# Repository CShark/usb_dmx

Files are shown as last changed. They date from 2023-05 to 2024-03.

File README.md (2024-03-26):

# USB ArtNET Interface

This project is a USB ArtNET interface with four ports, based on the STM32G484. It will register itself as an Ethernet Card using the CDC-NCM protocoll to be automatically recognized by most operating systems (except Windows 10, which needs some manual configuration). It will then bind the ArtNET-implementation to a configurable IP on that virtual ethernet card. The device can be configured either using ArtNET commands for software that supports this, using a web interface on the device and it can optionally be extended to include a display module for configuration directly at the device.

<p float="middle">
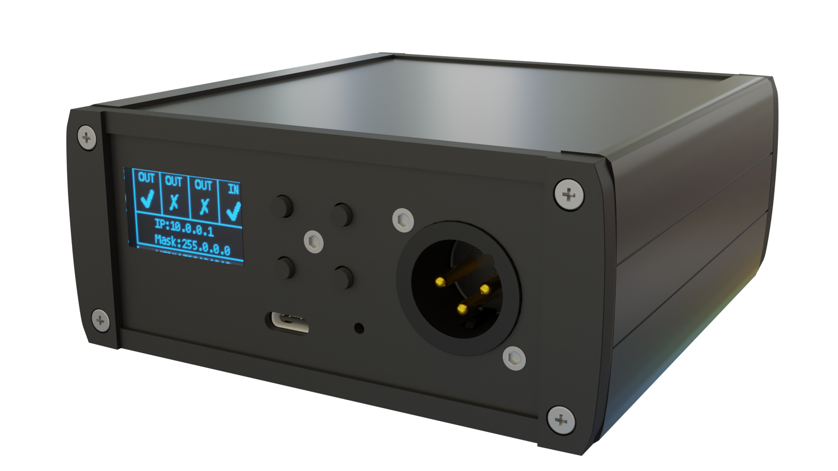
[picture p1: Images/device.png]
    
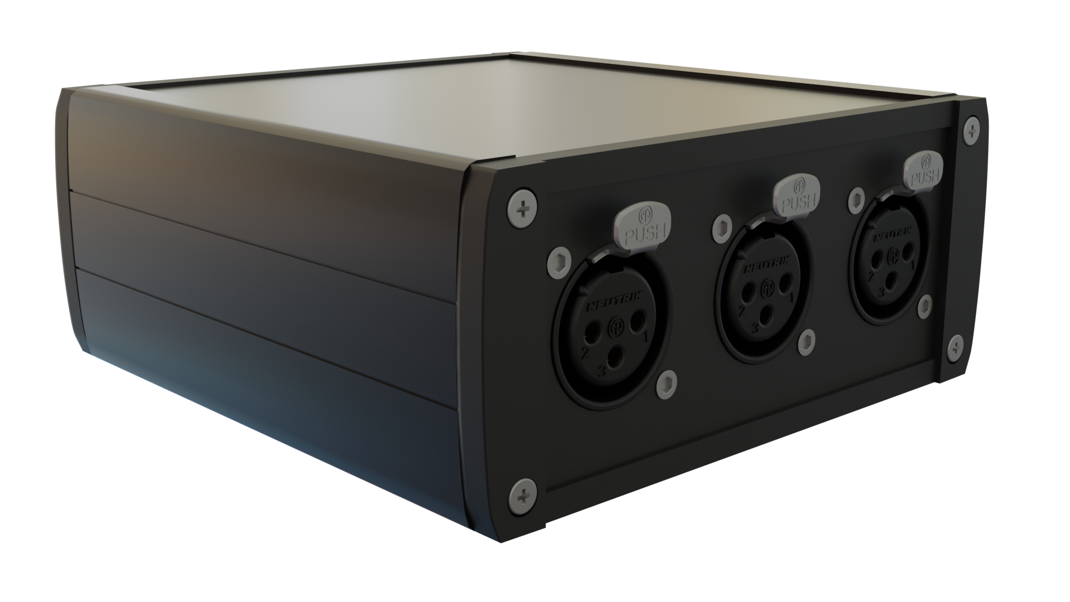
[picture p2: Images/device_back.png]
    
</p>
<p float="middle">
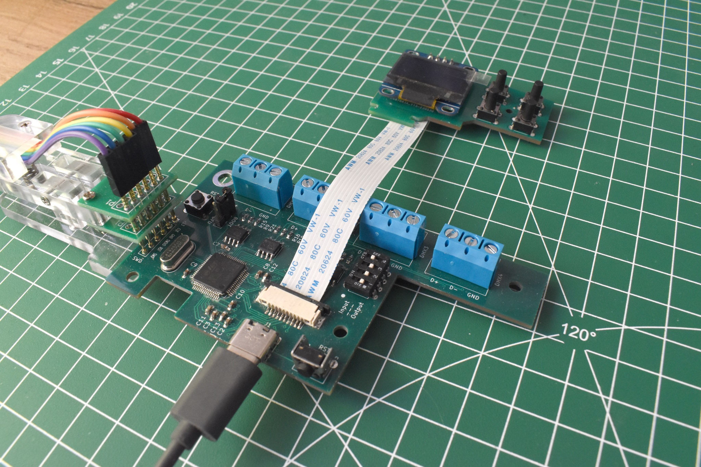
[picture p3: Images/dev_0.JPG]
    
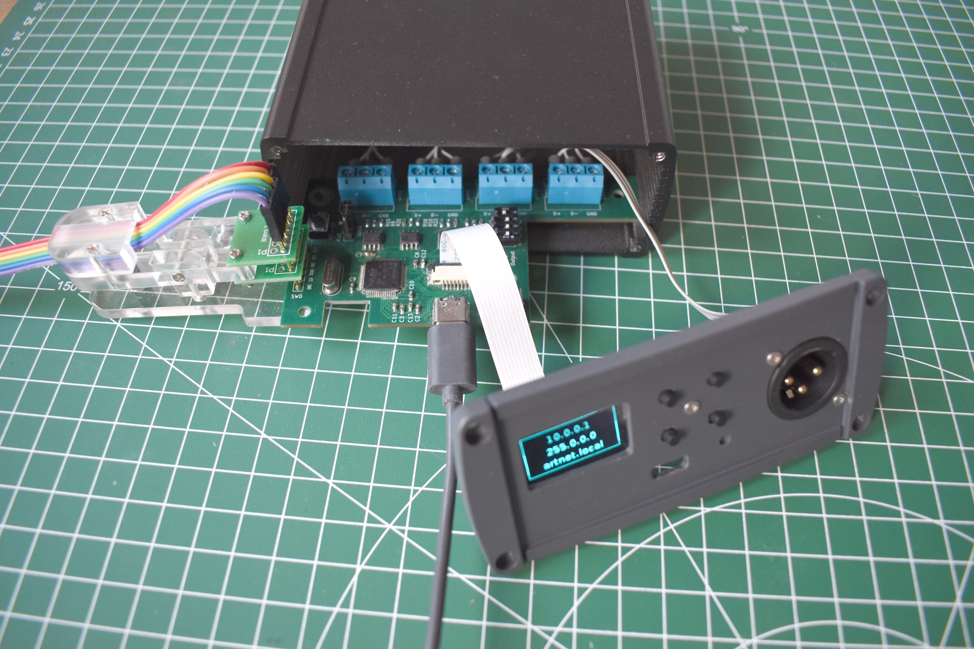
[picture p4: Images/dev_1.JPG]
    
</p>

## Schematic
The project uses an STM32G484RE, but should work with any STM32G4xxRE variant. The ports are controlled by a MAX3440E each, which will provide some ESD protection in addition to the TVS-Diodes. The device will draw around ~150mA, which is easily delivered by USB2.0 ports. Galvanic isolation was omitted because it needs too much space and because it is not recommended for the transmitting ports of DMX-Devices anyway (although it is recommended for receiving ports, but not mandatory).

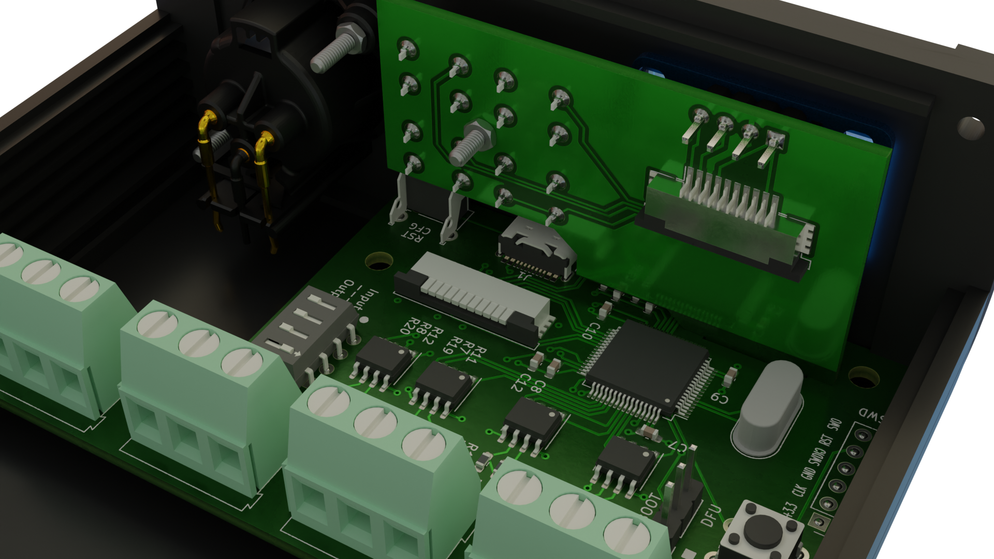
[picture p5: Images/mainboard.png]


## PCB
The PCB is designed as a four layer board, as with this small size the price was acceptable. The pcb was designed with a `TEKAL 31.29`-case from TEKO in mind, but any case with at least 100x100mm will work.  placing three ports at the rear and one port beside the usb port at the front of the case. The display module is completely optional and is designed to slot into the mainboard and is secured with an additional screw from the front. It is then connected using a 10-pin ribbon cable.

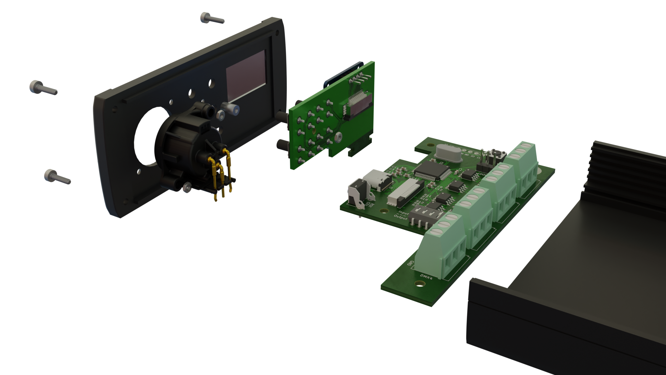
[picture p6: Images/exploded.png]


### BOM
The total cost for this device is currently aproximately 90€. Assembly takes around 6 hours, including soldering the boards, CNC the covers and soldering / crimping the connectors. You can save money by printing your own case (25€), finding a cheaper STM32G4xxRE variant at your local dealer (11€), finding cheaper XLR connectors (5€) and skipping on the display module (5€). 

<details>
<summary>Mainboard (~40€)</summary>

| Amount | Type | Value | Footprint |
|-|-|-|-|
| 4 | Capacitor | 1μF | 0603 |
| 7 | Capacitor | 100nF | 0603 |
| 2 | Capacitor | 20pF | 0603 |
| 1 | Capacitor | 10nF | 0603 |
| 1 | Capacitor | 4.7μF | 0603 |
| 8 | TVS Diode | | SMA |
| 1 | USB-C Receptacle | | |
| 1 | FFC Connector | | 1x10, Pitch 1mm |
| 4 | Terminal Block | | 1x3, Pitch 2.54mm |
| 1 | Pin Header | | 1x3, Pitch 2.54mm |
| 1 | Jumper | | 1x2, Pitch 2.54mm |
| 2 | Resistor | 5K1 | 0603 |
| 1 | Resistor | 4K7 | 0603 |
| 4 | Resistor | 130 | 0603 |
| 8 | Resistor | 560 | 0603 |
| 1 | Switch | | Through Hole, Height 6mm |
| 1 | Switch | | Through Hole, Angled, Height 6mm |
| 1 | DIP-Switch | | Through Hole, 2x4, Pitch 2.54mm |
| 1 | ESD Protection | ESDALD05UD4 | SOT23-6 |
| 1 | Linear Regulator | AP2112K-3.3 | SOT23-5 |
| 4 | Transceiver | MAX3440E | SOIC-8 |
| 1 | Crystal | 25MHz | HC49 |
| 1 | μC | STM32G484RE | LQFP64 |
    
</details>

<details>
<summary>Display Board (~5€)</summary>

| Amount | Type | Footprint |
|-|-|-|
| 1 | OLED-Display | 0.96" with I²C and SSD1306 compatible driver |
| 1 | FFC Connector | 1x10, Pitch 1mm |
| 2 | Resistor | 4K7 | 0603 |
| 4 | Switch | Through Hole, Height 10mm |
| 1 | FFC Cable | 1x10, Pitch 1mm, Length ~100mm, Type B (opposing-side contacts) |

</details>

<details>
<summary>Mechanical parts (~40€)</summary>

| Amount | Type | Specs |
|-|-|-|
| 1 | Case | TEKO TEKAL 31.29, or any case that takes Eurocard-sized PCBs (100x100mm) |
| 4 | XLR Connector | An individual mix of Female and Male XLR 3- and 5-Pin connectors, depending on your needs |
| 9 | Screws | M2, Length 15mm, Countersink |
| 9 | Nuts | M2 |
| 1 | Acrylic Window | 15mm x 25mm |
| 1 | Spacer | M2, Length 6mm |
| 1 | Mainboard PCB | | 
| 1 | Display PCB | |

</details>

Here are two lists on digikey that include all necessary components, except for the mechanical parts and the oled-display. It does contain four XLR-Connectors though.
- [Parts for the Mainboard](https://www.digikey.com/en/mylists/list/8UBRGNUC4X)
- [Parts for the Display-Module](https://www.digikey.com/en/mylists/list/5N5ETFD0BY)

## Firmware
The firmware is completely custom, only based on CMSIS (no HAL) and supports the important parts of the ArtNET protocol. Which port is an input and which an output can be set using the dip switches, but later be overwritten using either ArtNET commands, the WebUI or the display menu. The device also has a reset button to reset the configuration for when things go completely wrong. If the device is completely bricked it can be put into bootloader mode using a jumper on the mainboard.

The device supports mDNS and is always reachable using `artnet.local` in addition to its ip-address. The WebUI allows configuring each individual port with all the settings that ArtNET-Commands also support. You can also change the ip-configuration of the device and its internal minimal DHCP-Server, as well as clearing all settings, rebooting the device and switching the device into DFU/Bootloader mode to flash a new firmware.
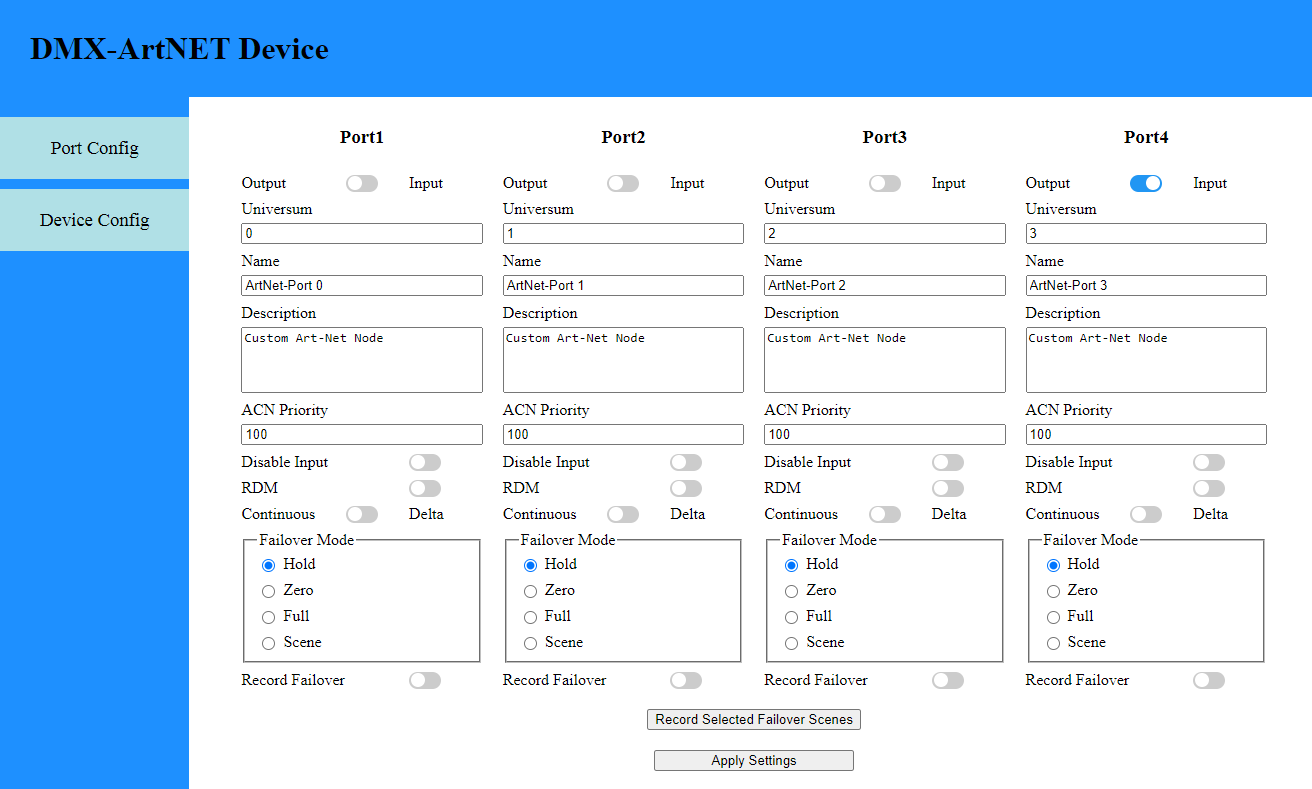
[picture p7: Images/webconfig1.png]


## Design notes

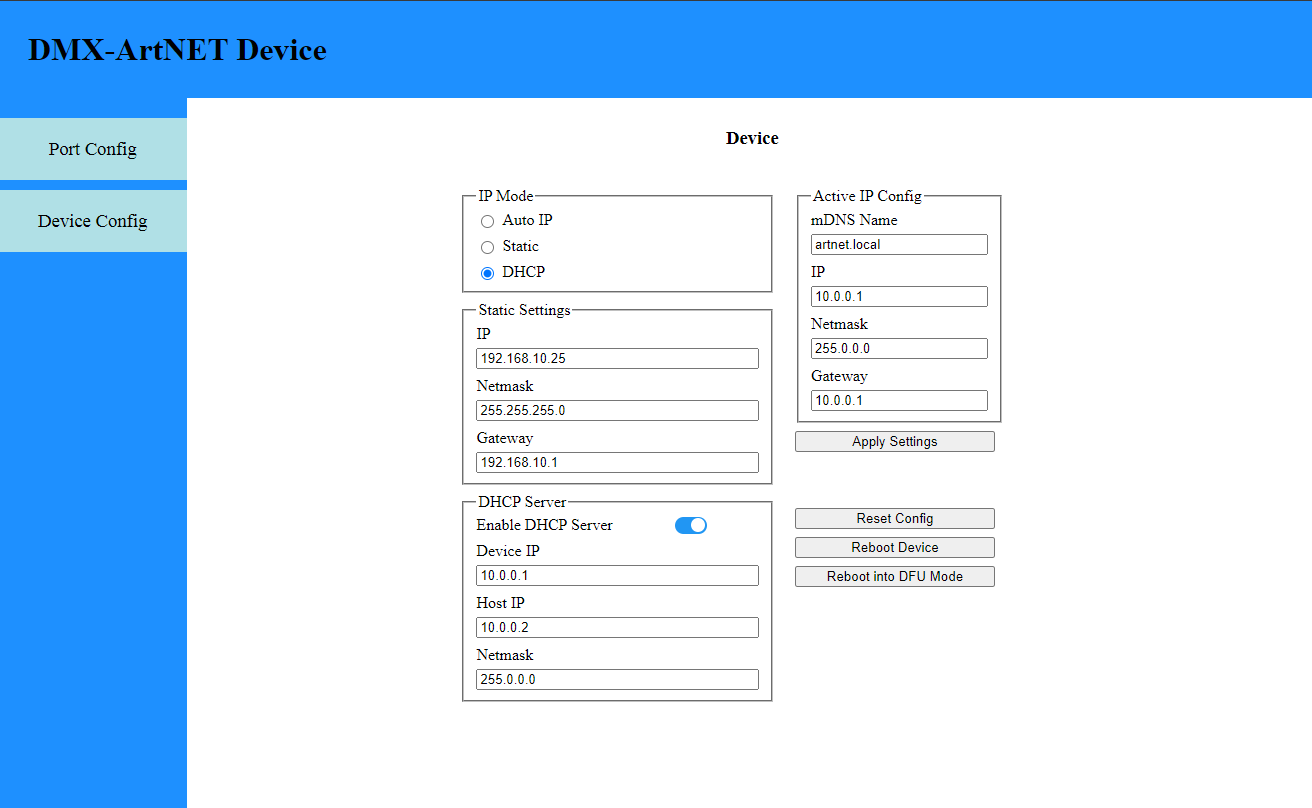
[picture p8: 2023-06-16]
Images/webconfig2.png

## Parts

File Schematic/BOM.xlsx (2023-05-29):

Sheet: DMX
# | Reference | Qty | Value | Footprint | DNP
1 | C1, C2, C13, C15 | 4 | 1μF | Capacitor_SMD:C_0603_1608Metric_Pad1.08x0.95mm_HandSolder
2 | C3, C4, C7, C8, C9, C10, C14 | 7 | 100nF | Capacitor_SMD:C_0603_1608Metric_Pad1.08x0.95mm_HandSolder
3 | C5, C6 | 2 | 20pF | Capacitor_SMD:C_0603_1608Metric_Pad1.08x0.95mm_HandSolder
4 | C11 | 1 | 10nF | Capacitor_SMD:C_0603_1608Metric_Pad1.08x0.95mm_HandSolder
5 | C12 | 1 | 4.7μF | Capacitor_SMD:C_0603_1608Metric_Pad1.08x0.95mm_HandSolder
6 | D5, D6, D7, D8, D9, D10, D11, D12 | 8 | D_TVS | Diode_SMD:D_SMA_Handsoldering
7 | J1 | 1 | USB_C_Receptacle_USB2.0 | Connector_USB:USB_C_Receptacle_HRO_TYPE-C-31-M-12
8 | J2 | 1 | Subboard | Connector_FFC-FPC:TE_1-84953-0_1x10-1MP_P1.0mm_Horizontal
9 | J3, J4, J5, J6 | 4 | DMX | TerminalBlock:TerminalBlock_Altech_AK300-3_P5.00mm
10 | J9 | 1 | Conn_01x01 | MountingHole:MountingHole_4.3mm_M4_DIN965_Pad
11 | JP1 | 1 | Jumper_3_Bridged12 | Connector_PinHeader_2.54mm:PinHeader_1x03_P2.54mm_Vertical
12 | R3, R4 | 2 | 5K1 | Resistor_SMD:R_0603_1608Metric_Pad0.98x0.95mm_HandSolder
13 | R5 | 1 | 4K7 | Resistor_SMD:R_0603_1608Metric_Pad0.98x0.95mm_HandSolder
14 | R7, R8, R9, R10 | 4 | 130 | Resistor_SMD:R_0603_1608Metric_Pad0.98x0.95mm_HandSolder
15 | R11, R12, R15, R16, R19, R20, R21, R22 | 8 | 560 | Resistor_SMD:R_0603_1608Metric_Pad0.98x0.95mm_HandSolder
16 | SW1 | 1 | SW_Push | Button_Switch_THT:SW_PUSH_6mm
17 | SW2 | 1 | SW_DIP_x04 | Package_DIP:DIP-8_W7.62mm
18 | SW3 | 1 | SW_Push | Button_Switch_THT:SW_Tactile_SPST_Angled_PTS645Vx39-2LFS
19 | U1 | 1 | ESDALD05UD4 | Package_TO_SOT_SMD:SOT-23-6_Handsoldering
20 | U2 | 1 | AP2112K-3.3 | Package_TO_SOT_SMD:SOT-23-5_HandSoldering
21 | U3 | 1 | STM32G474RET | Package_QFP:LQFP-64_10x10mm_P0.5mm
22 | U5, U6, U7, U8 | 4 | MAX3440E | Package_SO:SOIC-8_3.9x4.9mm_P1.27mm
23 | Y1 | 1 | 25MHz | Crystal:Crystal_HC18-U_Vertical

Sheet: DMX Subboard
# | Reference | Qty | Value | Footprint | DNP
1 | J1 | 1 | OLED | Connector_PinHeader_2.54mm:PinHeader_1x04_P2.54mm_Vertical
2 | J2 | 1 | Connector | Connector_FFC-FPC:TE_1-84952-0_1x10-1MP_P1.0mm_Horizontal
3 | SW1 | 1 | Back | Button_Switch_THT:SW_PUSH_6mm_H8.5mm
4 | SW2 | 1 | Up | Button_Switch_THT:SW_PUSH_6mm_H8.5mm
5 | SW3 | 1 | Down | Button_Switch_THT:SW_PUSH_6mm_H8.5mm
6 | SW4 | 1 | Confirm | Button_Switch_THT:SW_PUSH_6mm_H8.5mm

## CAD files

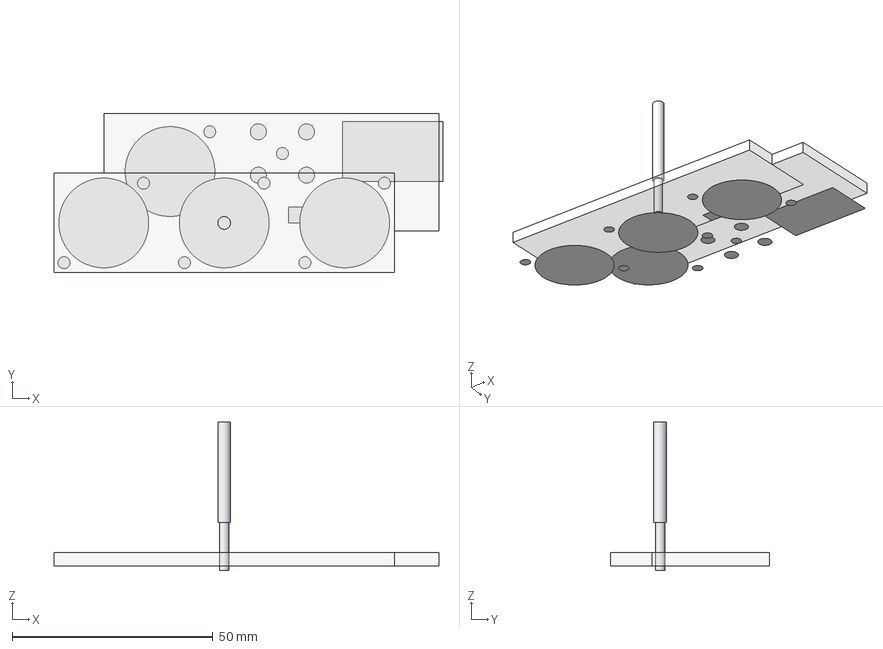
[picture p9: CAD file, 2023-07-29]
CAD/Cover.FCStd
96.9 x 39.7 x 42.0 mm
Front_Face
Back_Face
Stock001
Stock002
2.4mm Endmill001
2.4mm Endmill

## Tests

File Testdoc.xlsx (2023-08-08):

Settings (OLED) |  | Tests include functionality tests of the features cofigured
Port Config
Setting | Port
Short Name
Long Name
Port Direction
Universe
ACN Priority
Input Disable
RDM
Port Mode
Failover Mode
Record Failover
IP Config
IP Mode
Static IP
Netmask
Gateway
DHCP Server
Device IP
Host IP
DHCP Mask
General
Firmware Version
Firmware ID
Reset Config
Reboot into DFU
Overview shows IP & Netmask
Settings (Web) |  | Tests only check if settings are stored correctly, functionality is already tested
Port Config
Setting | Port
Short Name
Long Name
Port Direction
Universe
ACN Priority
Input Disable
RDM
Port Mode
Failover Mode
Record Failover
IP Config
IP Mode
Static IP
Netmask
Gateway
DHCP Server
Device IP
Host IP
DHCP Mask
General
Firmware Version
Firmware ID
Reset Config
Reboot into DFU
Reboot Device
IP Overview shows current IP settings
Functionality
Setting | Port
Basic Sending / Receiving
Fallback to Failover Mode
Disabling Input Signals
Delta / Continuous Port Mode
Universe Setting
Reset Config Button

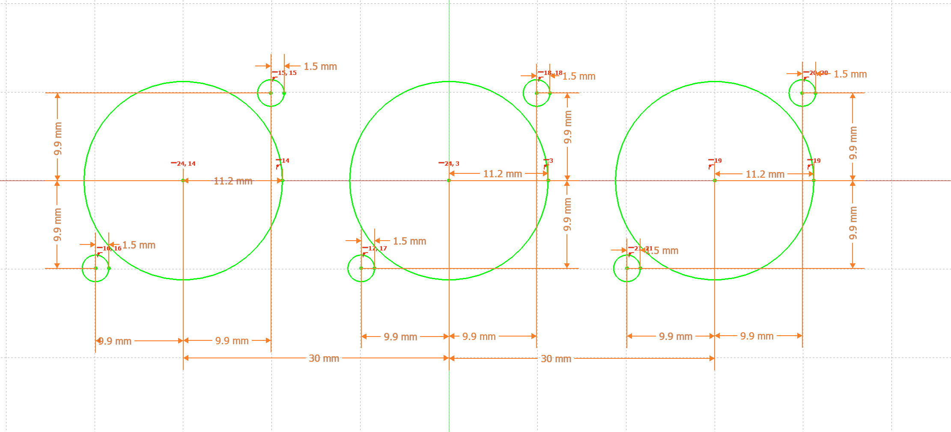
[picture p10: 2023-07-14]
CAD/Back_Measurement.png

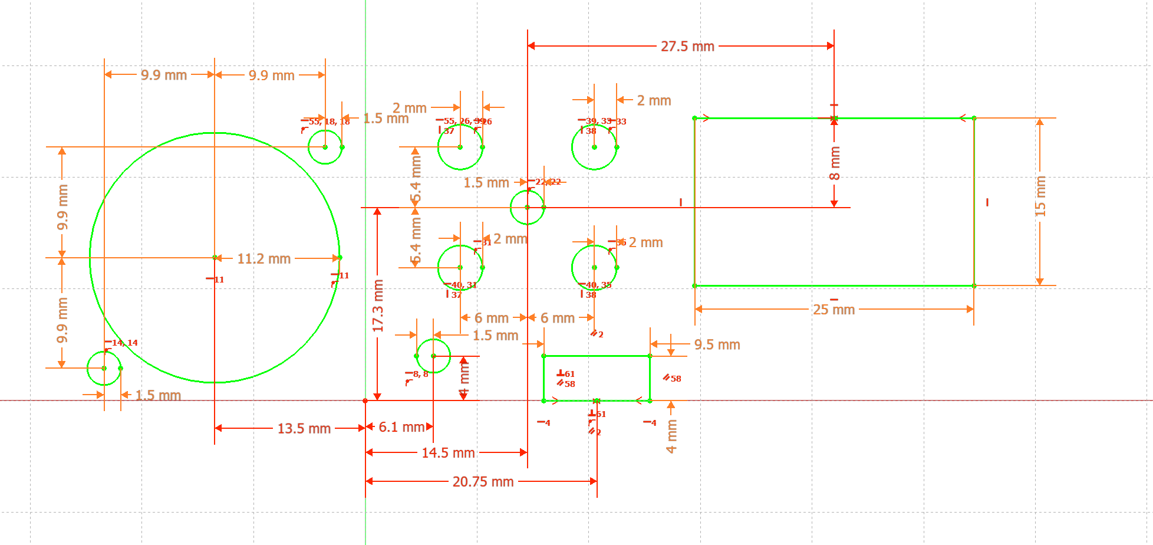
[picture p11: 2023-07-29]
CAD/Front_Measurement.png

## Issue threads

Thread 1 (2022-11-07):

Make device configurable using the resistors

CShark, 2022-11-07:
The Input & Output configuration should be configurable using the resistors. Add support.

Flole998, 2023-02-03:
@CShark What do you think about extending this a little to allow setting the configuration over USB/ArtNet/UDP packets and storing it in the EEPROM? If at boot a valid EEPROM entry with a matching checksum is found the resistors are ignored and the EEPROM setting is used instead. That sounds like a good idea to me, what do you think?

CShark, 2023-02-05:
Already (semi) done. The resistors will supply the default configuration after a config reset and you can use the Command field of the ArtAddress-Packet to overwrite the settings. Settings are currently (i.e. in the upcoming version) stored in a flash page at the end of the device.

The current version should be functionally done, I'm currently writing the tooling to manipulate and configure ArtNET devices. The latest ETA for a working implementation will be this easter, as I'll need it working by then :D

Closed 2022-12-01.

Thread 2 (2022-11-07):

ArtNET firmware

CShark, 2022-11-07:
Add an alternative firmware that emulates an ethernet card and provides ArtNET support to be even more flexible and don't have to rely on janky fixes to plugins on the software.

Flole998, 2023-02-08:
Have you checked the performance/latency of ArtNet vs. USB/FX5 clone? Especially when you want fast operations or quick changes on many channels some interfaces have issues.

I was thinking about implementing the protocol used by digital enlightenment for their USB interface as it allows selecting an operation mode and the protocol seems to be optimized for performance.

CShark, 2023-02-08:
Not yet. It is a little slow registering the USB Network driver compared to e.g. a mouse (takes a hot second), but after that I can't see any visible/perceivable lag at all. *Theoretically* a 150MHz core clock / 70MHz peripheral clock should be plenty fast compared to four times 30KiB/s using DMA. I do want to get the USB enumeration faster anyway, so I'm planning to do some profiling. Will include some USB-Packet to DMX-Output analysis in that session then.

CShark, 2023-02-08:
Regarding fx5 and digital enlightenment: the fx5 is just a commercialised version of the digital enlightenment device. And I had a couple of gripes with those devices.

1. Since a month ago or so, a win 11 update broke the output of all (3) my fx5 devices. I could only use the input ports, but the outputs didn't work, especially having multiple fx5 running. I'll try if they work again tomorrow...
2. If you only need output on windows you're fine. If you also need input, the device will tend to completely freeze from time to time, apparently related to how many other devices are on a specific USB controller (also internal ones). Linux does not have this problem. Had this happen every single time I went on tour with them for every single show. My laptop has issues after ~30min or <10min, depending on which side I plug it in. A stationary PC was mostly fine, only had it occasionally ~twice a year in about 60-70 hours of operation per year.

You can reset them pretty easily though, that's why I put up with them. But I would advise against using their input ports.

Closed 2023-02-18.

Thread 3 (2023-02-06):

Add RDM support

CShark, 2023-02-06:
Add support to manage RDM devices using ArtNET

517002650, 2024-04-20:
I don't know why RDM cannot be used, and the reset button cannot reset all parameters. I can only use the OLED screen to flip pages,

517002650, 2024-04-20:
I have processed both the PCB and board, and purchased and soldered the chip components. All other functions are normal, but the RDM cannot be used. The reset button cannot reset the configuration parameters back to default. I did not purchase and soldered the D3TVS components. Does the RDM function require soldering of the D3TVS components? I am very puzzled? There is another question. Is it possible for this chip to support direct connection with RZ45 Ethernet cable? USB virtual network card cannot achieve 8XL output

CShark, 2024-04-21:
Reset works for me. It is initiated either using the OLED-Screen or pressing and holding the reset button for at least 5s. But yeah, there is no visual confirmation, which would probably be a good thing to have... #8

CShark, 2024-04-21:
RDM is not yet implemented, thats why it won't work. The TVS-Diodes are not necessary for a working pcb and have nothing to do with RDM.

Currently I've already done a refactoring to allow for easy integration of the RDM functionality, but my main problem is that I don't have any device that supports RDM. I'd love to have it, but I currently have nothing solid to develop against. I could use a couple of Arduinos with some sketchy RDM, but I would prefer to have proper devices for testing.

I'll see if I can get some and push this feature a bit more in the next couple months.

Regarding Ethernet: That is currently out of scope in the near future. If I do ethernet, I'll either have to change the formfactor to accomodate the ethernet port and electronics or sacrifice a DMX port. And if I add Ethernet I'd also like to add PoE while I'm at it; I'm playing with the thought of building an alternate version but very probably not in the foreseeable future.

517002650, 2024-05-13:
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

Yes, the reset button is useful. You are right, you need to press and hold for about 5 seconds. I am currently encountering a problem where I am unable to modify and replace the host IP properly. After modifying and replacing the host IP, I am unable to obtain the IP address properly and need to reset repeatedly. Occasionally, I can successfully modify the IP. Why is the success rate of modifying the IP so low?, Will this issue still be fixed in the future, or will it be a problem with my operation?

517002650, 2024-05-13:
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

I am looking forward to launching RDM support. Can you provide me with an address so that I can send you some sections that support RDM for testing? I also hope to fix the issue of not being able to automatically obtain IP addresses after modifying the host IP, which is very unstable and has a low success rate.

517002650, 2024-05-29:
> 添加对使用 ArtNET 管理 RDM 设备的支持

> 添加对使用 ArtNET 管理 RDM 设备的支持

> Add support to manage RDM devices using ArtNET
Does version 2.1 of V5 support RDM?

CShark, 2024-05-29:
@517002650 No, not yet. It'll be in the next version.

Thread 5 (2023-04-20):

Ability to configure each output from let's say a web interface or some DIP switches (using binary for selecting the universe)

nt2ds, 2023-04-20:
I want to build this node but configuring each port through resistors and changing them day to day isn't the easiest thing.
Are the plans of adding a web interface to configure each port or adding DIP switches on the PCB to choose every port receives from which chip (MAX3440E)?

CShark, 2023-05-24:
Currently you can reconfigure the Input / Output using the supplied software and the resistors are only for the initial configuration after a hard reset.

Regarding Dip-Switches: In the future there might be a PCB reiteration to add USB-C instead of the USB-B connector, I'll see if I can replace the resistors with dip-switches then.

Regarding WebUI: Currently the memory is a _bit_ (very) tight, so I'm probably unable to add a webUI without a PCB-Revision. Will look into taking that into account if I do one though.

Regarding Remapping: Not sure why you'd want to do that? I mean, you can just redefine the ArtNET Universe to either send to a different port or let the port receive a different Universe, so it is already remappable through software.

CShark, 2023-06-16:
PCB revision is done, WebUI is also done (66b1ba0). Has now dip-switches for the config reset state and a WebUI for reconfiguration instead of that janky tool.

Closed 2023-06-16.

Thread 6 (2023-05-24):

PCB Revision 2

CShark, 2023-05-24:
The PCB needs some changes to properly accommodate all planned functions, now that I have some experience with the current iteration.

Planned changes:
- USB-C connector instead of USB-B
- Reset-Button to reset the device configuration without the need of any software
- Add more SRAM to support proper RDM and a webinterface and get rid of the janky configuration tool
- Upgrade μC to at least STM32G474RET6 for more memory leeway
- Change Resistor configuration to DIP-Array (will still be only for the initial state of the device & remain reconfigurable)

Closed 2023-05-29.

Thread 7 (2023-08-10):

Empty submodule folder & Ethernet Jack

AlexSmith2025, 2023-08-10:
I want to repeat your project. where can i get the missing file folders?   lwip     And is it possible to make not a USB but an Internet connector.  thanks my mail smith.show2025@gmail.com

CShark, 2023-08-12:
Hey, lwip is a submodule from another repo, you'll have to initialize it using `git submodule update --init --recursive`

As for Ethernet, it is currently out of scope for my personal needs.  You'd have to remove a port on the front to make room for an ethernet port and add a separate MAC/PHY, because the STM32G4 series does not have MII support. If you want to support PoE in addition you'll also have to add the specific magnetics, PoE negotiation chips and a power fallback circuit.

It does sound like a nice challenge though. Maybe I'll revisit it in a couple of years.

Closed 2023-11-08.

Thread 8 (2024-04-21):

Visual feedback on reset

CShark, 2024-04-21:
Add visual feedback when holding the reset button triggers a reset. Either reboot or a short message on the OLED.

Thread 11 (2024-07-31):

ioc file from the STM32CubeMX

folny, 2024-07-31:
Hi

Can you please add the .ioc file from the STM32CubeMX program to the project ?. I would like to modify your project for a different type of processor and it would be easier for me.

CShark, 2024-08-01:
Sorry, I don't have it anymore.. It was just an empty CubeProject without any configuration though, as I configured everything in code and just needed the CMSIS and some initalization files. Not sure if that would be of any help even if I had it :/

The biggest change will probably be the usb peripheral though, as the [USB-memory works differently on different devices](https://github.com/CShark/stm32usb/wiki/03.-USB-Reset#31-usb-sram).

For the clocktree you'll just have to make sure to fix the enabled subcircuit-addresses if they change. The USART and DMA-mapping can be altered directly in the usart header/config, without digging in the code (ideally...)

folny, 2024-08-01:
Thank you for your reply

So I will try what I can, I also want to ask which library I can use instead of lwip@bef26c4 because it is unavailable.

CShark, 2024-08-02:
Sure. If you have any questions regarding the adjustment of the configuration feel free to ask.

Regarding lwip: It works for me. After cloning the directory will be empty, because it is a submodule (i.e. the git repository is somewhere else). You can initialize the the lwip-submodule by running `git submodule update --init`

folny, 2024-08-02:
Thanks for the advice, everything is working now. I bought this development board and I would like to modify your project for it, how can I change the processor type in the STM32CubeIDE program as easily as possible ?. I use Keil ARM for my projects and I don't know all the features in STM32CubeIDE.

https://github.com/WeActStudio/WeActStudio.STM32G474CoreBoard

CShark, 2024-08-02:
To do these adjustments, you'll have to do the following to the code.

## CubeMX
To get an overview of the necessary changes, open the CubeMX-Tool (which is a separate download - or grab the info from the datasheet, but thats way more work..)

You won't need the generated code, but it's an easy way to reference the configuration and make sure nothing clashes.

1. Select your Processor (STM32G474CEU6)
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
then double click one of the two entries.

2. Enable all Peripherals
Under Connectivity, select two Usarts that are convenient for you and enable them by setting their Mode to `Asynchronous`. Also enable the USB.

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

This will show you which pins to use for which peripheral when wiring things up. Check if the selected ones are also exposed on the breadboard.

3. Enable Clock
Under SystemClock > RCC, set HSE to `Crystal/Ceramic Resonator`
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

4. Configure Clock
Go to Clock Configuration and select `No`. The main clock for this board seems to be 8MHz, so we can leave the Input Frequency. Now adjust the PLL until the sysclock has 144MHz. (M=1, N=36, /R=2, /Q=6 seems fine).

## main.c
1. Adjust Clock_Init with the values as displayed in CubeMX. The correct register values for the parameters are in the RCC-Section of the datasheet for the PLLCFGR-Register

2. Adjust peripheral clocks. I don't know if the clocktree is exactly the same or where the peripherals you picked are located, so make sure to enable their respective clock.

3. Adjust GPIO_Init to set the ports and alternate modes correctly

4. Replace ReadPortConfig with a fixed initial value for your input/outputs

## usart.c
1. Change the first two entries according to your configuration. For DRPort/DRPin, pick any that are free. They go to RE/DE of the RS485-Transceiver.

## Regarding only 2 ports
Actually probably a good idea to make that a constant somewhere...

For now, you'll have to search all files for the string ' < 4' and adjust it to ' < 2' to reduce the number of ports. That _should_ be safe, I think...

If you want to adjust the webpage as well, you'll have to adjust the Inc/eth/fs/index.html and replace the ' < 4' in there as well. After that, run the index.html through a minifier, copy that into the min directory and get a copy of the "makefsdata" tool from lwip to run it on that min directory.

folny, 2024-08-02:
Thanks for the great advice, I'll try it all out soon and let you know how it goes.

md-light, 2024-08-09:
Hi

I couldn't run your project on this board, so I'm asking if you could take a look at it and write me how to set the clock and GPIO parameters exactly according to the attached file. I will be very grateful for your help.

[STM32G474_USB_ArtNet_DMX.zip](https://github.com/user-attachments/files/16564511/STM32G474_USB_ArtNet_DMX.zip)

folny, 2024-08-09:
Hi

I couldn't run your project on this board, so I'm asking if you could take a look at it and write me how to set the clock and GPIO parameters exactly according to the attached file. I will be very grateful for your help.

[STM32G474_USB_ArtNet_DMX.zip](https://github.com/user-attachments/files/16565734/STM32G474_USB_ArtNet_DMX.zip)

CShark, 2024-08-14:
I don't have a board, so I can't verify anything I say 😅

For the first step, I would comment everything in `main.c` starting at `GPIO_Init()`, so that only the clock and systick are initialized. In `Clock_Init`, I'd comment everything between "Select & Enable IO Clocks" and the while loop. A Breakpoint after `Clock_Init` allows you to inspect the variable "SystemCoreClock", which will hold the `Sysclk` in Hertz, which should be `144000000`.

Having a quick glance, the value for PLLN seems wrong (23, should be 36 according to cube clock tree). PLLM also seems wrong; by setting `RCC_PLLCFGR_PLLM_0` you set the PLLM-Value to `01`, which should be `/2` if memory serves me correct. Removing that value to leave PLLM at `00` should set it to `/1`.

If you run into the HardFault handler, there is probably something wrong with the high-speed transition (Every HCLK > ~75Mhz or something needs to adjust the flash access speeds). To verify this is the cause, you can then comment the block "Select PLL as main clock...." except for the first line directly following that comment. This will turn of the high speed transition and leave the HCLK at half the SYSCLK. To fix it, you'll have to consult the datasheet for the chip on how to exactly transition into high speed on that chip.

If the `SystemCoreClock`-Variable holds the correct value, the clock is configured and working as expected.

The next step will be to enable the peripheral clocks again (the block you commented out after "Select & Enable IO Clocks"). It should work as is, if there are no compile errors. If there are, the register layout changed and needs to be adjusted.

If that works, you can start with the peripherals. I can do another writeup for where in the datasheet the required information for the register configuration is.

CShark, 2024-08-23:
Hm, that is unfortunate. Debugging USB is always half a pain in the butt.

Some pointers to get started and finding out what's going on:
1. Generally don't place any breakpoints after `USB_Init` was called until the enumeration is completed. USB has a pretty tight timing and any breakpoint will result in a failed enumeration.
2. Now break rule 1 😀. Place a breakpoint in line 348 of `usb.c`, it should be just below the `case 0x05: // Set Address`-line. This breakpoint will verify if communication even works at all.

If you hit the breakpoint, there is probably something wrong with the descriptor. Get a copy of the [Thesycon USB Descriptor Dumper](https://www.thesycon.de/eng/usb_descriptordumper.shtml) and post the log of the enumeration process. This tool will record the enumeration and all the device descriptors and also tell if something is wrong with them.

If you don't hit the breakpoint, my guess is that the clock speed for the USB-Subcircuit is not configured correctly. If your main sysclk is running at the expected 144MHz, check the PPLQ-settings (should divide by 6) and your CK48-Clock Mux (should be set to PLLQ). To verify an issue with your PLLQ-value, you can also temporarly switch the CK48 clock mux to HSI48 (don't forget to enable it in RCC_CRRCR). It's less reliable, but works. If it still doesn't hit that breakpoint, make sure the subcircuit is even enabled (USBEN in one of the RCC_APBxENRx-Registers)

If that doesn't lead to any new data, I'll have to think some more.

folny, 2024-08-26:
The problem is only in the clock settings, when I replaced the 8Mhz resonator with a 25Mhz one, everything started working.

remidavidkoster, 2025-05-19:
@folny I'm in the same boat - trying to run this on an STM32G474CE, but having the USB device descriptor request fail regardless of the PLL / Clock settings. It was just a matter of changing the crystal to a 25MHZ version? Would you be open to share your code for the device?

CShark, 2025-05-22:
I did some quick reconstruction;
According to CubeMX, when you run with a 8MHz Clock instead of 25MHz, you need the following clock adjustments:

```
PLL-M: 2 > 1
PLL-N: 23 > 36
```

Which means changing the line

`RCC->PLLCFGR |= RCC_PLLCFGR_PLLSRC_HSE | RCC_PLLCFGR_PLLM_0 | (23 << RCC_PLLCFGR_PLLN_Pos) | RCC_PLLCFGR_PLLQ_1;`
to
`RCC->PLLCFGR |= RCC_PLLCFGR_PLLSRC_HSE | (36 << RCC_PLLCFGR_PLLN_Pos) | RCC_PLLCFGR_PLLQ_1;`

This will result in a core frequency of `144MHz` instead of `143.75MHz`, the USB-subcircuit will get `48MHz` instead of `47.916MHz` and a USART-Speed of `72MHz` instead of `71.875MHz`.

In `usart.c`, adjust the `USART_BRR` to `(288 << 1)`, which will result in a flat `250KHz` instead of `250.871KHz` without the adjustment and `250.436KHz` with a 25MHz clock. The other constant can stay as it is.

CShark, 2025-06-04:
@remidavidkoster That could be possible, but not with that little SRAM. It needs at least 45KiB of SRAM to work - the network stack requires a "huge" amount of ram to work properly and I've already skimmed it down quite a bit. Maybe there is some more optimization potential by playing around with the lwipopts,h. For flash, you'll only need around 80KiB for the release build. The debug build needs a bit more.

Adjusting the number of universes: Either just leave it as is and only wire up one UART or search for the string "< 4" and adjust all if statements to read "< 1", which will disable all other outputs *except in the web UI*. There is currently no easy way to adjust the number of ports, but adding a constant is on my radar, but might take long time 'till I get to that.

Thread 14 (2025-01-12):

Config Reset and DFU on the same Switch

MicroMarty, 2025-01-12:
Is it possible, without changing the code, to combine the two functions of resetting the configuration and entering DFU mode on the same tactile switch?
If pressed during boot, it starts in DFU mode; if pressed while the system is running, the configuration is restored.
I made a quick diagram to illustrate this, and I'll try to test it with what I have.
Thanks!

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

Closed 2025-02-01.

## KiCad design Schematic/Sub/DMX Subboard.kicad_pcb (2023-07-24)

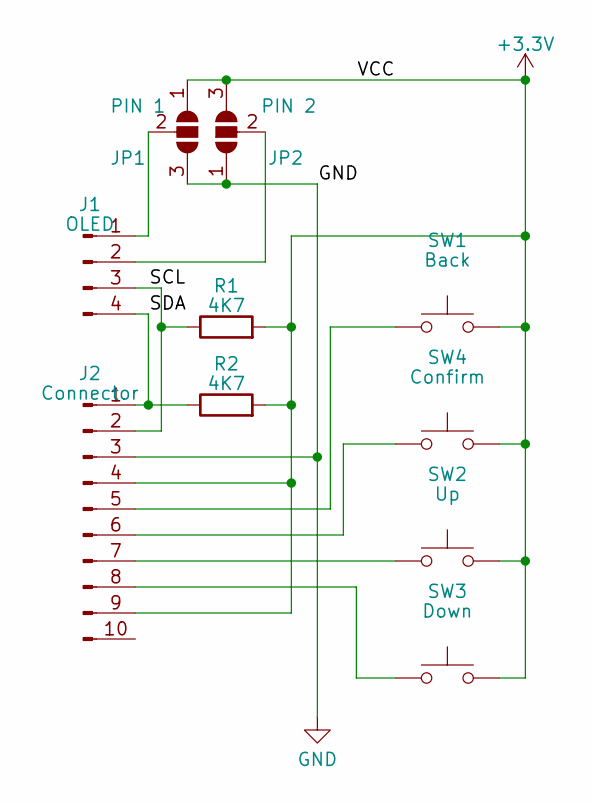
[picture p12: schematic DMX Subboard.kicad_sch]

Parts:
J1: OLED; PinHeader_1x04_P2.54mm_Vertical
J2: Connector; TE_1-84952-0_1x10-1MP_P1.0mm_Horizontal
JP1: PIN 1; SolderJumper-3_P2.0mm_Open_TrianglePad1.0x1.5mm
JP2: PIN 2; SolderJumper-3_P2.0mm_Open_TrianglePad1.0x1.5mm
R1, R2: 4K7; R_0603_1608Metric_Pad0.98x0.95mm_HandSolder
SW1: Back; SW_PUSH_6mm_H8.5mm
SW2: Up; SW_PUSH_6mm_H8.5mm
SW3: Down; SW_PUSH_6mm_H8.5mm
SW4: Confirm; SW_PUSH_6mm_H8.5mm

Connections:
+3.3V: J2.4, J2.9, JP1.1 (A), JP2.3 (B), R1.2, R2.2, SW1.2, SW2.2, SW3.2, SW4.2
/SCL: J1.3, J2.2, R1.1
/SDA: J1.4, J2.1, R2.1
GND: J2.3, JP1.3 (B), JP2.1 (A)
unnamed: J1.1, JP1.2 (C)
unnamed: J1.2, JP2.2 (C)
unnamed: J2.5, SW1.1
unnamed: J2.6, SW4.1
unnamed: J2.7, SW2.1
unnamed: J2.8, SW3.1

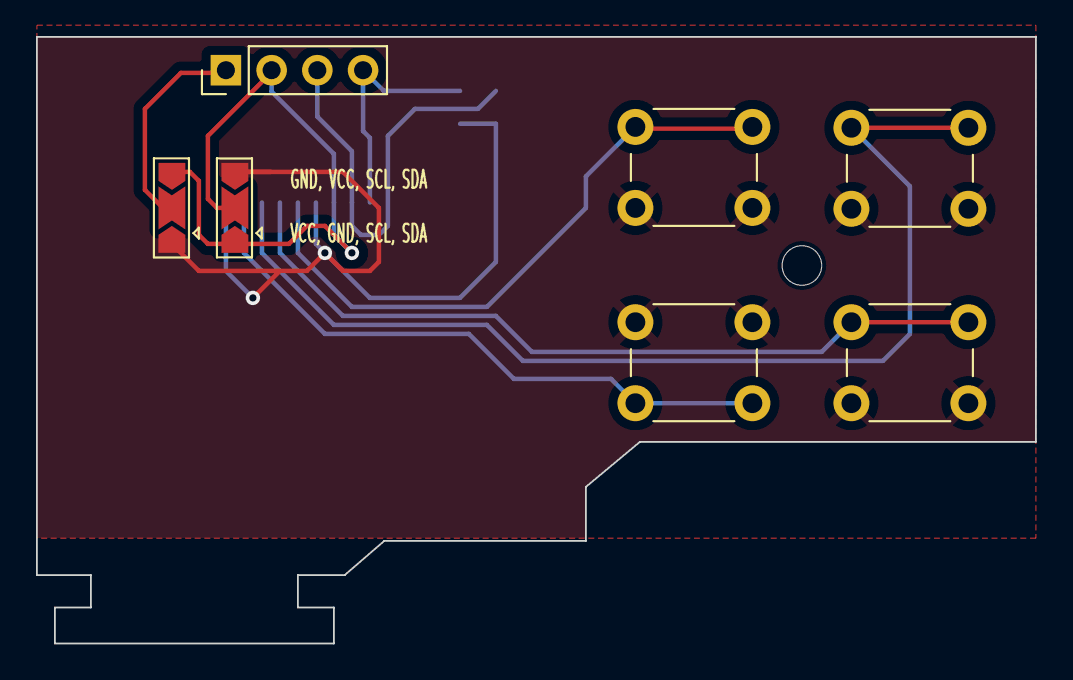
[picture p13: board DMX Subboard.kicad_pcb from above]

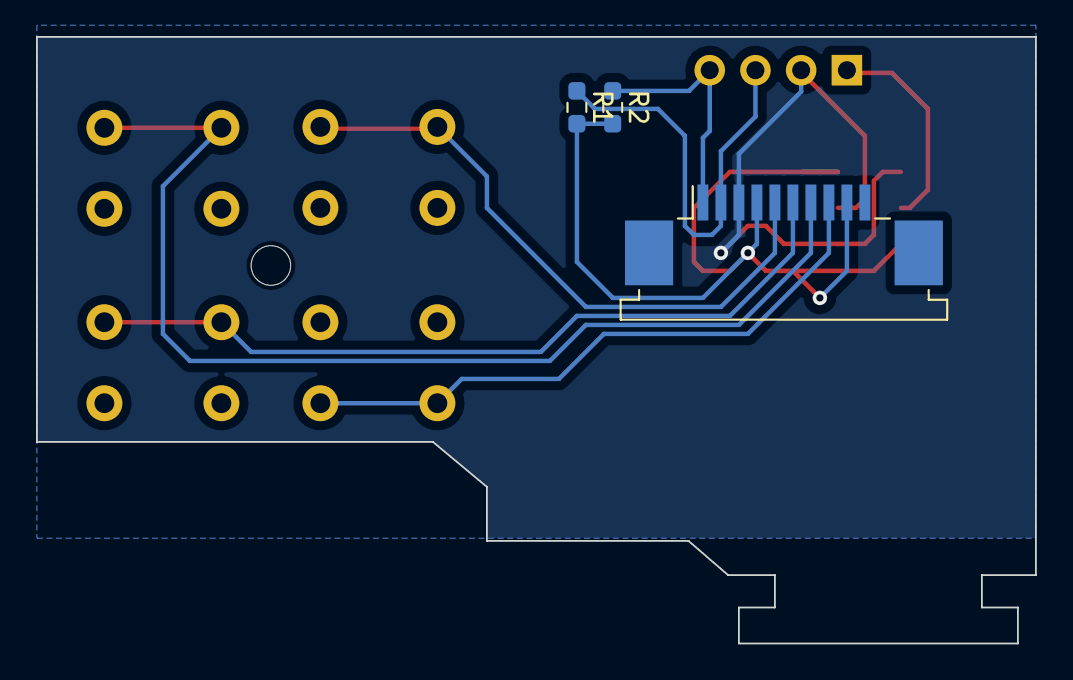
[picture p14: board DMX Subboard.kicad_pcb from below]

Board: 2 copper layers, 55.5 x 33.7 mm, 10 parts (3 on the bottom side), 10 nets.

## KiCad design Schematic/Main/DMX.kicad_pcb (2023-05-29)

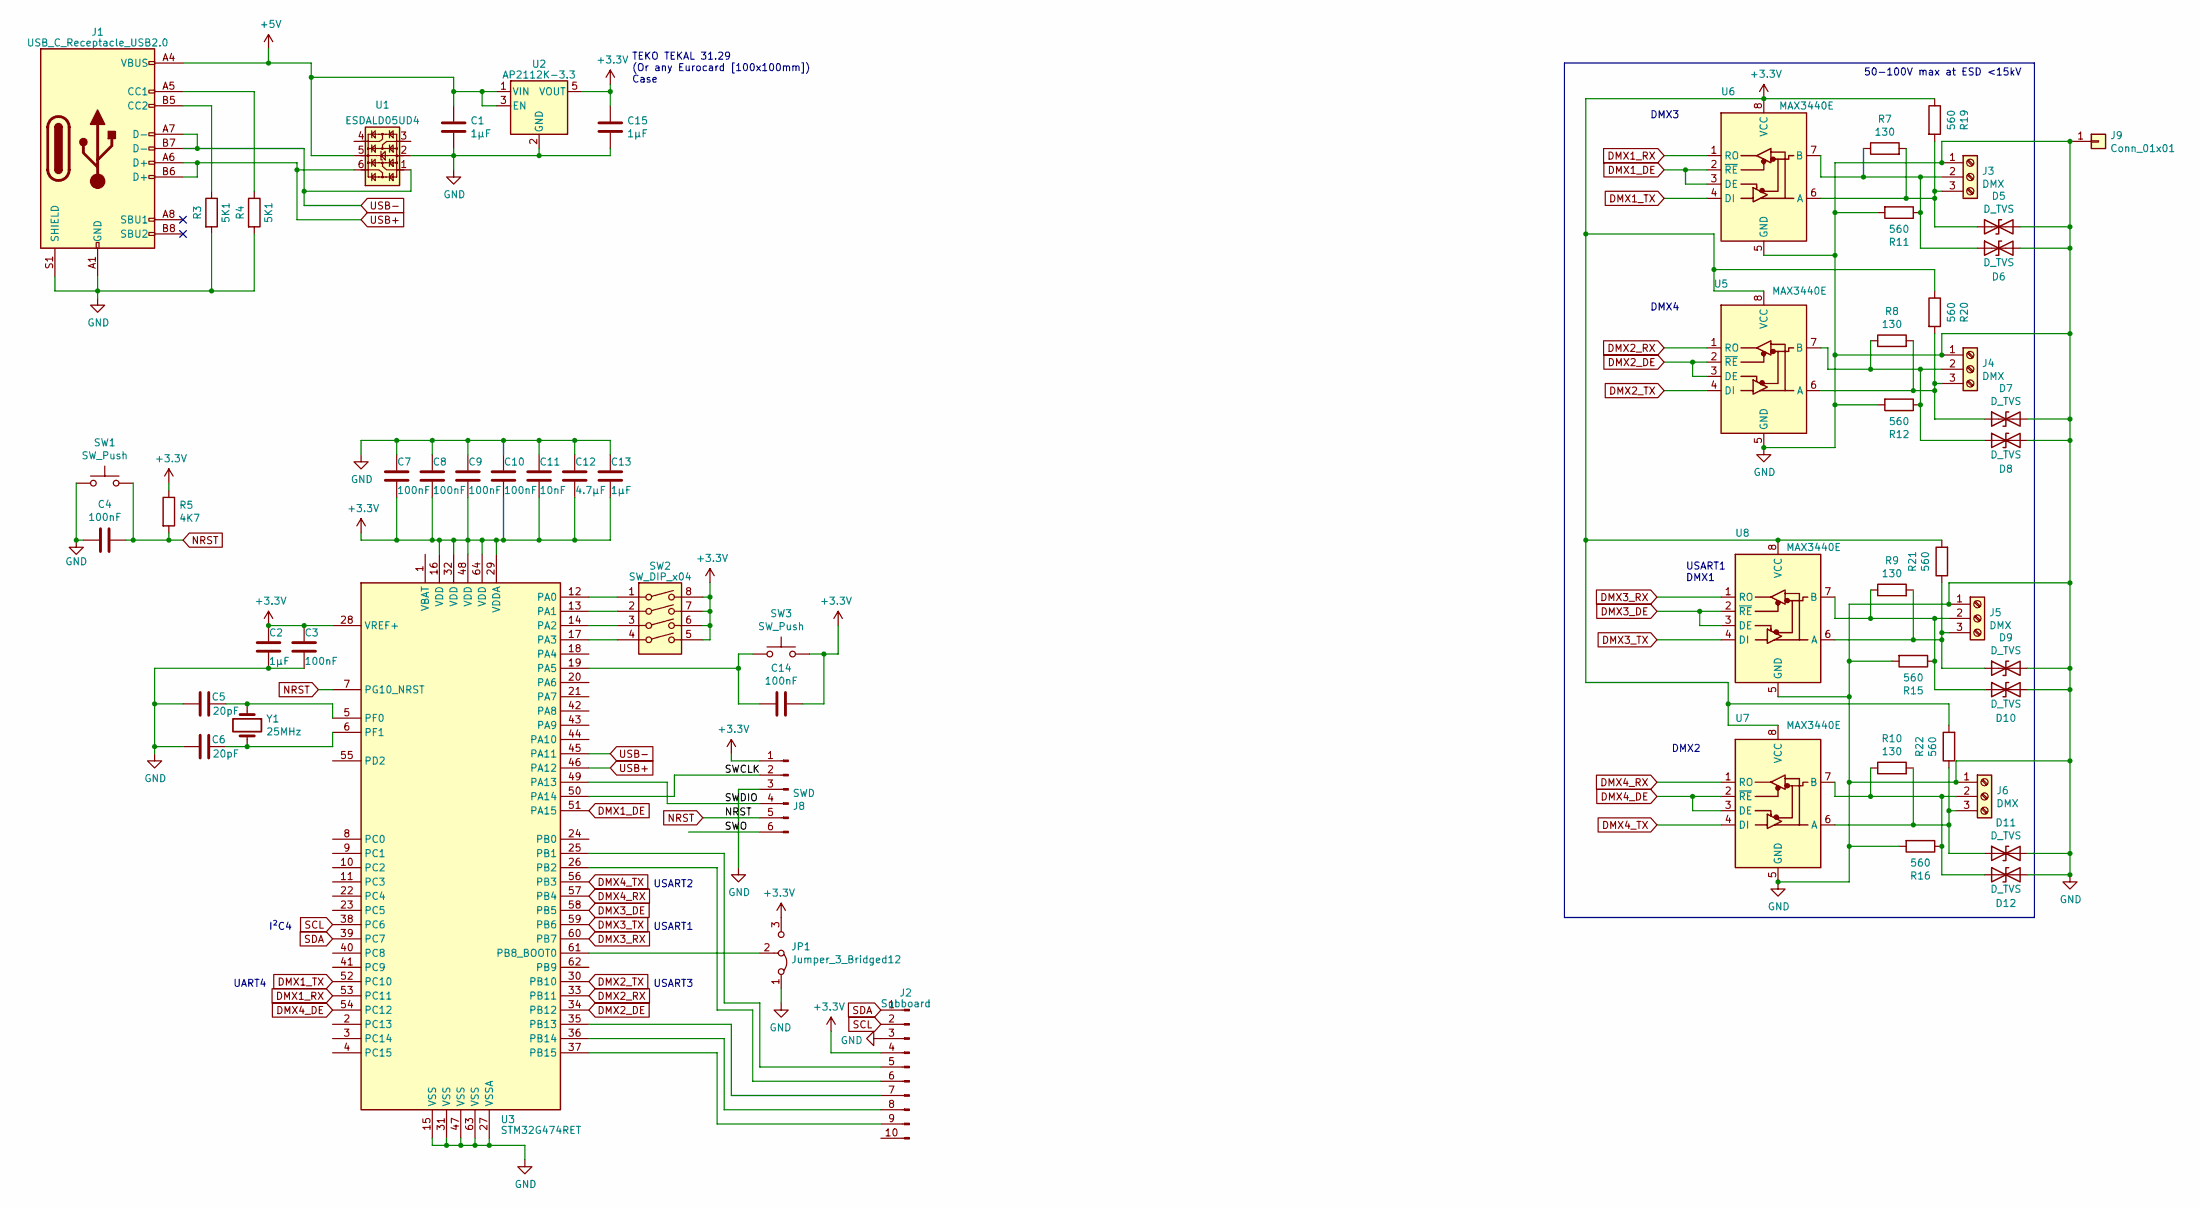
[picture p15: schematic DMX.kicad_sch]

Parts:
C1, C2, C13, C15: 1μF; C_0603_1608Metric_Pad1.08x0.95mm_HandSolder
C3, C4, C7, C8, C9, C10, C14: 100nF; C_0603_1608Metric_Pad1.08x0.95mm_HandSolder
C5, C6: 20pF; C_0603_1608Metric_Pad1.08x0.95mm_HandSolder
C11: 10nF; C_0603_1608Metric_Pad1.08x0.95mm_HandSolder
C12: 4.7μF; C_0603_1608Metric_Pad1.08x0.95mm_HandSolder
D5, D6, D7, D8, D9, D10, D11, D12: D_TVS; D_SMA_Handsoldering
J1: USB_C_Receptacle_USB2.0; USB_C_Receptacle_HRO_TYPE-C-31-M-12
J2: Subboard; TE_1-84953-0_1x10-1MP_P1.0mm_Horizontal
J3, J4, J5, J6: DMX; TerminalBlock_Altech_AK300-3_P5.00mm
J8: SWD; PinHeader_1x06_P2.54mm_Vertical
J9: Conn_01x01; MountingHole_4.3mm_M4_DIN965_Pad
JP1: Jumper_3_Bridged12; PinHeader_1x03_P2.54mm_Vertical
R3, R4: 5K1; R_0603_1608Metric_Pad0.98x0.95mm_HandSolder
R5: 4K7; R_0603_1608Metric_Pad0.98x0.95mm_HandSolder
R7, R8, R9, R10: 130; R_0603_1608Metric_Pad0.98x0.95mm_HandSolder
R11, R12, R15, R16, R19, R20, R21, R22: 560; R_0603_1608Metric_Pad0.98x0.95mm_HandSolder
SW1: SW_Push; SW_PUSH_6mm
SW2: SW_DIP_x04; DIP-8_W7.62mm
SW3: SW_Push; SW_Tactile_SPST_Angled_PTS645Vx39-2LFS
U1: ESDALD05UD4; SOT-23-6_Handsoldering
U2: AP2112K-3.3; SOT-23-5_HandSoldering
U3: STM32G474RET; LQFP-64_10x10mm_P0.5mm
U5, U6, U7, U8: MAX3440E; SOIC-8_3.9x4.9mm_P1.27mm
Y1: 25MHz; Crystal_HC18-U_Vertical

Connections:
+3V3: C2.1, C3.1, C7.2, C8.2, C9.2, C10.2, C11.2, C12.2, C13.2, C14.2, C15.1, J2.4, J8.1, JP1.3 (B), R5.1, R19.1, R20.1, R21.2, R22.2, SW2.5, SW2.6, SW2.7, SW2.8, SW3.1, U2.5 (VOUT), U3.16 (VDD), U3.28 (VREF+), U3.29 (VDDA), U3.32 (VDD), U3.48 (VDD), U3.64 (VDD), U5.8 (VCC), U6.8 (VCC), U7.8 (VCC), U8.8 (VCC)
+5V: C1.1, J1.A4 (VBUS), J1.A9 (VBUS), J1.B4 (VBUS), J1.B9 (VBUS), U1.5, U2.1 (VIN), U2.3 (EN)
/SWCLK: J8.2, U3.50 (PA14)
/SWDIO: J8.4, U3.49 (PA13)
/SWO: J8.6
DMX1_DE: U3.51 (PA15), U6.2 (~RE), U6.3 (DE)
DMX1_RX: U3.53 (PC11), U6.1 (RO)
DMX1_TX: U3.52 (PC10), U6.4 (DI)
DMX2_DE: U3.34 (PB12), U5.2 (~RE), U5.3 (DE)
DMX2_RX: U3.33 (PB11), U5.1 (RO)
DMX2_TX: U3.30 (PB10), U5.4 (DI)
DMX3_DE: U3.58 (PB5), U8.2 (~RE), U8.3 (DE)
DMX3_RX: U3.60 (PB7), U8.1 (RO)
DMX3_TX: U3.59 (PB6), U8.4 (DI)
DMX4_DE: U3.54 (PC12), U7.2 (~RE), U7.3 (DE)
DMX4_RX: U3.57 (PB4), U7.1 (RO)
DMX4_TX: U3.56 (PB3), U7.4 (DI)
GND: C1.2, C2.2, C3.2, C4.2, C5.2, C6.2, C7.1, C8.1, C9.1, C10.1, C11.1, C12.1, C13.1, C15.2, D5.2 (A2), D6.2 (A2), D7.2 (A2), D8.2 (A2), D9.2 (A2), D10.2 (A2), D11.2 (A2), D12.2 (A2), J1.A1 (GND), J1.A12 (GND), J1.B1 (GND), J1.B12 (GND), J1.S1 (SHIELD), J2.3, J3.1, J4.1, J5.1, J6.1, J8.3, J9.1, JP1.1 (A), R3.2, R4.2, R11.2, R12.2, R15.2, R16.2, SW1.1, U1.2, U2.2 (GND), U3.15 (VSS), U3.27 (VSSA), U3.31 (VSS), U3.47 (VSS), U3.63 (VSS), U5.5 (GND), U6.5 (GND), U7.5 (GND), U8.5 (GND)
NRST: C4.1, J8.5, R5.2, SW1.2, U3.7 (PG10_NRST)
unnamed: D5.1 (A1), J3.3, R7.2, R19.2, U6.6 (A)
unnamed: D6.1 (A1), J3.2, R7.1, R11.1, U6.7 (B)
unnamed: D7.1 (A1), J4.3, R8.2, R20.2, U5.6 (A)
unnamed: D8.1 (A1), J4.2, R8.1, R12.1, U5.7 (B)
unnamed: D9.1 (A1), J5.3, R9.2, R21.1, U8.6 (A)
unnamed: D10.1 (A1), J5.2, R9.1, R15.1, U8.7 (B)
unnamed: D11.1 (A1), J6.3, R10.2, R22.1, U7.6 (A)
unnamed: D12.1 (A1), J6.2, R10.1, R16.1, U7.7 (B)
unnamed: J1.A5 (CC1), R4.1
unnamed: J1.B5 (CC2), R3.1
unnamed: J2.5, U3.25 (PB1)
unnamed: J2.6, U3.26 (PB2)
unnamed: J2.7, U3.35 (PB13)
unnamed: J2.8, U3.36 (PB14)
unnamed: J2.9, U3.37 (PB15)
unnamed: JP1.2 (C), U3.61 (PB8_BOOT0)
unnamed: SW2.1, U3.12 (PA0)
unnamed: SW2.2, U3.13 (PA1)
unnamed: SW2.3, U3.14 (PA2)
unnamed: SW2.4, U3.17 (PA3)
unnamed: C14.1, SW3.2, U3.19 (PA5)
unnamed: C5.1, U3.5 (PF0), Y1.1
unnamed: C6.1, U3.6 (PF1), Y1.2
SCL: J2.2, U3.38 (PC6)
SDA: J2.1, U3.39 (PC7)
USB+: J1.A6 (D+), J1.B6 (D+), U1.6, U3.46 (PA12)
USB-: J1.A7 (D-), J1.B7 (D-), U1.1, U3.45 (PA11)

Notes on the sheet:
I²C4
USART1 DMX1
50-100V max at ESD <15kV
TEKO TEKAL 31.29 (Or any Eurocard [100x100mm]) Case
USART3
UART4
DMX4
USART2
DMX2
DMX3
USART1

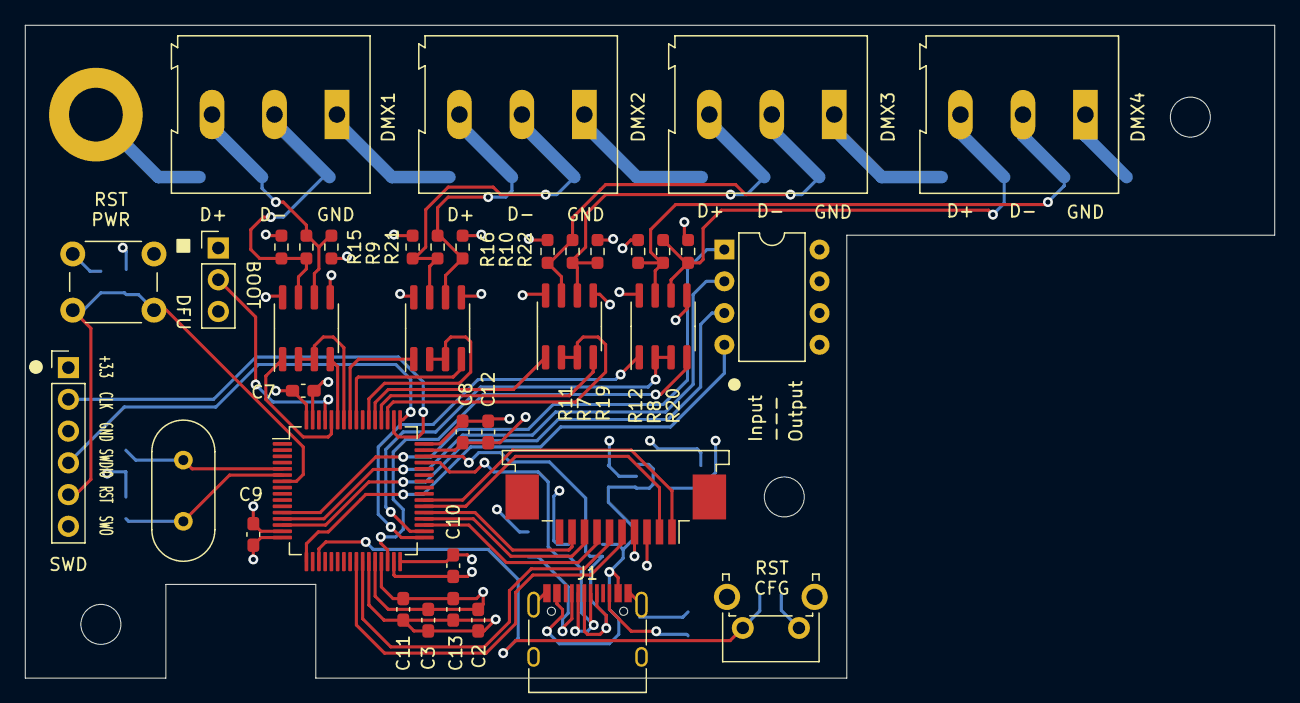
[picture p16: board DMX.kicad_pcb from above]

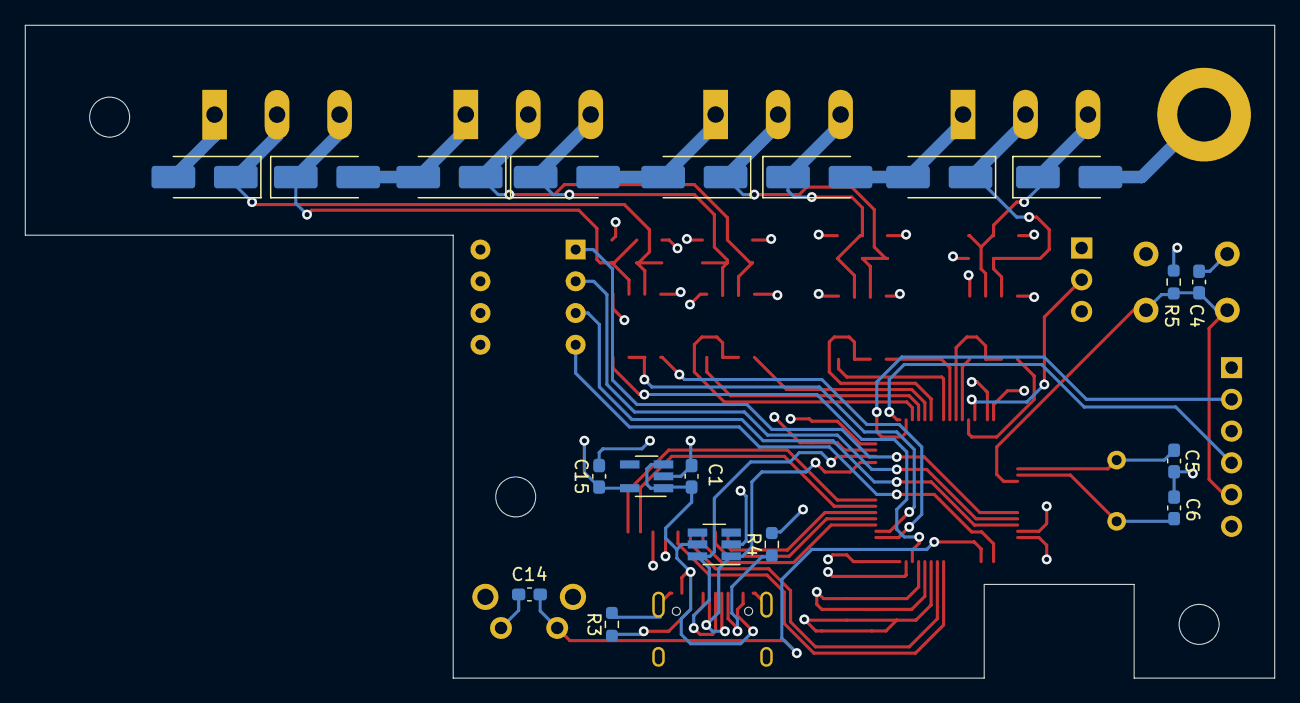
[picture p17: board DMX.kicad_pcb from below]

Board: 4 copper layers, 100.0 x 52.2 mm, 58 parts (20 on the bottom side), 45 nets.

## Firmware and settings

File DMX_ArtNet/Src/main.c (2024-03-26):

#include "main.h"
#include "config.h"
#include "eth/artnet.h"
#include "eth/dhcp_server.h"
#include "eth/http_custom.h"
#include "eth/ncm_netif.h"
#include "lwip/apps/httpd.h"
#include "lwip/apps/mdns.h"
#include "lwip/igmp.h"
#include "lwip/init.h"
#include "lwip/netif.h"
#include "lwip/timeouts.h"
#include "ncm_device.h"
#include "oled/oled.h"
#include "profiling.h"
#include "systimer.h"
#include "usart.h"
#include "usb.h"

static void Clock_Init(void);
static void GPIO_Init(void);
static void ReadPortConfig(void);

static unsigned char portConfig[] = {0, 0, 0, 0};
static struct netif ncm_if;

/**
 * @brief  The application entry point.
 * @retval int
 */
int main(void) {
    // Jump to bootloader triggered
    RCC->APB1ENR1 |= RCC_APB1ENR1_PWREN;
    RCC->APB2ENR |= RCC_APB2ENR_SYSCFGEN;
    if (TAMP->BKP0R == 0xF0) {
        PWR->CR1 |= PWR_CR1_DBP;
        TAMP->BKP0R = 0x00;
        PWR->CR1 &= ~PWR_CR1_DBP;
        SYSCFG->MEMRMP |= 0x01;
        void (*SysMemBootJump)(void) = (void (*)(void))(*((unsigned long *)(STM32_SYSMEM + 4)));
        __set_MSP(*(unsigned long *)STM32_SYSMEM);
        SysMemBootJump();
    }

    Clock_Init();
    Systick_Init();
    GPIO_Init();

    USB_Init();

    lwip_init();
    httpd_init();
    igmp_init();
    mdns_resp_init();

    netif_add(&ncm_if, IP4_ADDR_ANY, IP4_ADDR_ANY, IP4_ADDR_ANY, NULL, ncm_netif_init, netif_input);
    netif_set_default(&ncm_if);
    netif_set_up(&ncm_if);

    ReadPortConfig();

    DhcpServer_Init();
    Config_Init(&ncm_if, portConfig);
    USART_Init(Config_GetActive());
    ArtNet_Init(&ncm_if);
    httpc_init(&ncm_if);

    igmp_start(&ncm_if);
    mdns_resp_add_netif(&ncm_if, "artnet", 3600);

    OLED_Init();

    unsigned int last_inputTick = 0;
    unsigned int last_forcedInputTick = 0;
    unsigned int resetTimer = 0;

    while (1) {
        ncm_netif_poll(&ncm_if);

        if (sys_now() - last_inputTick > 24) {
            if (sys_now() - last_forcedInputTick > 1000) {
                ArtNet_InputTick(1);
                last_forcedInputTick = sys_now();
            } else {
                ArtNet_InputTick(0);
            }

            NCM_FlushTx();
            last_inputTick = sys_now();
        }

        sys_check_timeouts();
        ArtNet_TimeoutTick();
        httpc_timeout();
        OLED_Tick();

        // Reset button
        if (GPIOA->IDR & (1 << 5)) {
            if (resetTimer != 0) {
                if (sys_now() - resetTimer > 5000) {
                    Config_Reset();
                    resetTimer = 0;
                }
            } else {
                resetTimer = sys_now();
            }
        } else {
            resetTimer = 0;
        }

        USART_Tick();
    }
}

/**
 * @brief Get the configuration for each port based on the dip switches
 * @details
 * GND = Output
 * 3.3V = Input
 */
static void ReadPortConfig() {
    // Enable inputs on PortA0..3 with pull down
    GPIOA->MODER &= ~(GPIO_MODER_MODE0_Msk | GPIO_MODER_MODE1_Msk | GPIO_MODER_MODE2_Msk | GPIO_MODER_MODE3_Msk);
    GPIOA->PUPDR |= GPIO_PUPDR_PUPD0_1 | GPIO_PUPDR_PUPD1_1 | GPIO_PUPDR_PUPD2_1 | GPIO_PUPDR_PUPD3_1;

    // detect configuration, port mapping is reverse to ports
    for (int i = 0; i < 4; i++) {
        if ((GPIOA->IDR & (1 << (3 - i))) != 0) {
            portConfig[i] = ARTNET_INPUT;
        } else {
            portConfig[i] = ARTNET_OUTPUT;
        }
    }

    // Disable Ports
    GPIOA->MODER |= (GPIO_MODER_MODE0_Msk | GPIO_MODER_MODE1_Msk | GPIO_MODER_MODE2_Msk | GPIO_MODER_MODE3_Msk);
}

/**
 * @brief System Clock Configuration
 * @retval None
 */
static void Clock_Init(void) {
    RCC->CR |= RCC_CR_HSEON | RCC_CR_HSION;

    // Configure PLL (R=143.75, Q=47.92)
    RCC->CR &= ~RCC_CR_PLLON;
    while (RCC->CR & RCC_CR_PLLRDY) {
    }
    RCC->PLLCFGR |= RCC_PLLCFGR_PLLSRC_HSE | RCC_PLLCFGR_PLLM_0 | (23 << RCC_PLLCFGR_PLLN_Pos) | RCC_PLLCFGR_PLLQ_1;
    RCC->PLLCFGR |= RCC_PLLCFGR_PLLREN | RCC_PLLCFGR_PLLQEN;
    RCC->CR |= RCC_CR_PLLON;

    // Select PLL as main clock, AHB/2, Wait and then transition into boost mode
    RCC->CFGR |= RCC_CFGR_HPRE_3 | RCC_CFGR_SW_PLL;
    PWR->CR5 &= ~PWR_CR5_R1MODE;
    unsigned int latency = FLASH->ACR;
    latency &= ~0xFF;
    latency |= 4;
    FLASH->ACR = latency;
    while ((FLASH->ACR & FLASH_ACR_LATENCY_Msk) != 4) {
    }
    RCC->CFGR &= ~RCC_CFGR_HPRE_3;

    // Select & Enable IO Clocks (PLL > USB, ADC; PLLC (71.875) > UART & I²C)
    RCC->CCIPR = RCC_CCIPR_CLK48SEL_1 | RCC_CCIPR_ADC12SEL_1;
    RCC->AHB2ENR |= RCC_AHB2ENR_ADC12EN | RCC_AHB2ENR_GPIOAEN | RCC_AHB2ENR_GPIOBEN | RCC_AHB2ENR_GPIOCEN;
    RCC->APB1ENR1 |= RCC_APB1ENR1_USBEN | RCC_APB1ENR1_UART4EN | RCC_APB1ENR1_USART3EN | RCC_APB1ENR1_USART2EN | RCC_APB1ENR1_TIM2EN;
    RCC->APB1ENR2 |= RCC_APB1ENR2_I2C4EN;
    RCC->APB2ENR |= RCC_APB2ENR_USART1EN;

    // Enable DMAMUX & DMA1 Clock
    RCC->AHB1ENR |= RCC_AHB1ENR_DMAMUX1EN | RCC_AHB1ENR_DMA1EN | RCC_AHB1ENR_DMA2EN;

    // Configure RTC-Clock for Backup registers, if necessary
    RCC->APB1ENR1 |= RCC_APB1ENR1_PWREN;
    if ((RCC->BDCR & RCC_BDCR_RTCEN) == 0) {
        PWR->CR1 |= PWR_CR1_DBP;
        RCC->BDCR |= 0x02 << RCC_BDCR_RTCSEL_Pos;
        RCC->BDCR |= RCC_BDCR_RTCEN;
        PWR->CR1 &= ~PWR_CR1_DBP;
    }

    while ((RCC->CFGR & RCC_CFGR_SWS_Msk) != RCC_CFGR_SWS_PLL) {
    }

    SystemCoreClockUpdate();
}

/**
 * @brief GPIO Initialization Function
 * @param None
 * @retval None
 */
static void GPIO_Init(void) {
    /*  PA
        5 > Config Reset
        11 & 12 > USB
        13 & 14 > SWDIO & SWCLK
        15 > DMX 1 Direction Output
     */
    GPIOA->MODER &= ~(GPIO_MODER_MODE15 | GPIO_MODER_MODE5);
    GPIOA->MODER |= GPIO_MODER_MODE15_0;
    GPIOA->PUPDR &= ~(GPIO_PUPDR_PUPD15);
    GPIOA->PUPDR |= GPIO_PUPDR_PUPD5_1;

    /* PB
      1, 2, 13, 14 > OLED Navigation
      15 > OLED Sense
      3 & 4 > DMX 4 TX,RX
      5,6,7 > DMX 3 DE,TX,RX
      8 > BOOT0
      10,11,12 > DMX 2 TX,RX,DE
     */
    GPIOB->AFR[0] = (7 << GPIO_AFRL_AFSEL3_Pos) | (7 << GPIO_AFRL_AFSEL4_Pos) | (7 << GPIO_AFRL_AFSEL6_Pos) | (7 << GPIO_AFRL_AFSEL7_Pos);
    GPIOB->AFR[1] = (7 << GPIO_AFRH_AFSEL10_Pos) | (7 << GPIO_AFRH_AFSEL11_Pos);
    GPIOB->MODER &= ~(GPIO_MODER_MODE1 | GPIO_MODER_MODE2 | GPIO_MODER_MODE3 | GPIO_MODER_MODE4 | GPIO_MODER_MODE5 | GPIO_MODER_MODE6 | GPIO_MODER_MODE7 | GPIO_MODER_MODE8 | GPIO_MODER_MODE10 | GPIO_MODER_MODE11 | GPIO_MODER_MODE12 | GPIO_MODER_MODE13 | GPIO_MODER_MODE14 | GPIO_MODER_MODE15);
    GPIOB->MODER |= GPIO_MODER_MODE3_1 | GPIO_MODER_MODE4_1 | GPIO_MODER_MODE5_0 | GPIO_MODER_MODE6_1 | GPIO_MODER_MODE7_1 | GPIO_MODER_MODE10_1 | GPIO_MODER_MODE11_1 | GPIO_MODER_MODE12_0;
    GPIOB->PUPDR |= GPIO_PUPDR_PUPD1_1 | GPIO_PUPDR_PUPD2_1 | GPIO_PUPDR_PUPD4_0 | GPIO_PUPDR_PUPD7_0 | GPIO_PUPDR_PUPD11_0 | GPIO_PUPDR_PUPD13_1 | GPIO_PUPDR_PUPD14_1 | GPIO_PUPDR_PUPD15_1;

    /* PC
      6, 7 > I²C SCL, SDA OLED
      10,11 > DMX 1 TX,RX
      12  > DMX 4 DE
     */
    GPIOC->AFR[0] = (8 << GPIO_AFRL_AFSEL6_Pos) | (8 << GPIO_AFRL_AFSEL7_Pos);
    GPIOC->AFR[1] = (5 << GPIO_AFRH_AFSEL10_Pos) | (5 << GPIO_AFRH_AFSEL11_Pos);
    GPIOC->MODER &= ~(GPIO_MODER_MODE6 | GPIO_MODER_MODER7 | GPIO_MODER_MODE10 | GPIO_MODER_MODE11 | GPIO_MODER_MODE12);
    GPIOC->MODER |= GPIO_MODER_MODER6_1 | GPIO_MODER_MODER7_1 | GPIO_MODER_MODE10_1 | GPIO_MODER_MODE11_1 | GPIO_MODER_MODE12_0;
    GPIOC->PUPDR |= GPIO_PUPDR_PUPD11_0;
}

void NMI_Handler() {
}

void HardFault_Handler() {
    while (1) {
    }
}

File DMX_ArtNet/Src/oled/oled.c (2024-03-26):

#include "oled/oled.h"
#include "config.h"
#include "dmx.h"
#include "lwip/netif.h"
#include "oled/fonts.h"

static void OLED_InitSendData(const unsigned char *buffer, unsigned short len, void (*callback)());
static void OLED_SendData(const unsigned char *buffer, unsigned short len);

static void OLED_RenderBoot();
static void OLED_RenderDFU();
static void OLED_RenderIpOverview();

static void OLED_NavigateMenu(OLED_Buttons btn);
static void OLED_RenderMenu();
static void OLED_NavigateEdit(OLED_Buttons btn);
static void OLED_RenderEdit();
static void OLED_NavigateValueSelect(OLED_Buttons btn);
static void OLED_RenderValueSelect();
static void OLED_NavigateEditSelect(OLED_Buttons btn);
static void OLED_RenderEditSelect();
static void OLED_NavigateConfirm(OLED_Buttons btn);
static void OLED_RenderConfirm();
static void OLED_RenderInvalidValue();

static void OLED_InitPort();
static void OLED_InitIp();
static void OLED_InitFirmware();

static void OLED_ConfirmPort();
static void OLED_ConfirmIp();
static void OLED_ConfirmReset();

static char OLED_ValidateFieldValue(unsigned char i);

static const unsigned char *pending_buffer;
static unsigned short pending_len;
static void (*pending_callback)();

static unsigned int lastTick;
static unsigned int bootTimer;
static unsigned int lastInputTick;
static unsigned int lastInputRepeatTick;
static unsigned int dfuTimer;
static unsigned int inputRepeatTimer;
static unsigned char forceRefresh = 0;

static char *opt_disabled[] = {"Disabled", "Enabled"};
static char *opt_yesno[] = {"No", "Yes"};
static char *opt_ipMode[] = {"AutoIP", "Static", "DHCP"};
static char *opt_portDir[] = {"Output", "Input"};
static char *opt_portMode[] = {"Cont", "Delta"};
static char *opt_failover[] = {"Hold", "Zero", "Full", "Scene"};

// needs to be separate, otherwise it will hartfault...
static char *listItems[] = {
    // Menu - 8
    "Port 1",
    "Port 2",
    "Port 3",
    "Port 4",
    "IP Config",
    "Firmware Info",
    "Reset Config",
    "Reboot DFU",
    // Ports - 10
    "Name",
    "Description",
    "Direction",
    "Universe",
    "ACN Prio",
    "In Disable",
    "RDM",
    "Port Mode",
    "Failover",
    "Rec Failover",
    // IP Config - 8
    "Mode",
    "Static IP",
    "Netmask",
    "Gateway",
    "DHCP Server",
    "Device IP",
    "Host IP",
    "DHCP Mask",
    // Firmware - 2
    "Version",
    "Firmware Id",
};

static OLED_ScreenData oledScreens[] = {
    {
        .OnRender = OLED_RenderBoot,
        .OnNavigate = NULL,
        .OnInit = NULL,
    },
    {
        .OnRender = OLED_RenderIpOverview,
        .OnNavigate = OLED_NavigateMenu,
        .OnInit = NULL,
    },
    {
        .OnRender = OLED_RenderMenu,
        .OnNavigate = OLED_NavigateMenu,
        .OnInit = NULL,
        .ListItems = &listItems[0],
        .ListSize = 8,
    },
    {
        .OnRender = OLED_RenderEdit,
        .OnNavigate = OLED_NavigateEdit,
        .OnInit = OLED_InitPort,
        .OnConfirm = OLED_ConfirmPort,
        .ListItems = &listItems[8],
        .ListSize = 10,
    },
    {
        .OnRender = OLED_RenderEdit,
        .OnNavigate = OLED_NavigateEdit,
        .OnInit = OLED_InitIp,
        .OnConfirm = OLED_ConfirmIp,
        .ListItems = &listItems[8 + 10],
        .ListSize = 8,
    },
    {
        .OnRender = OLED_RenderEdit,
        .OnNavigate = OLED_NavigateMenu,
        .OnInit = OLED_InitFirmware,
        .ListItems = &listItems[8 + 10 + 8],
        .ListSize = 2,
    },
    {
        .OnRender = OLED_RenderConfirm,
        .OnNavigate = OLED_NavigateConfirm,
        .OnConfirm = OLED_ConfirmReset,
        .OnInit = NULL,
    },
    {
        .OnRender = OLED_RenderDFU,
        .OnNavigate = NULL,
        .OnInit = NULL,
    },
};

static OLED_Transition oledTransitionMap[] = {
    {.Source = &oledScreens[1], .MenuItem = -1, .Target = &oledScreens[2]},

    {.Source = &oledScreens[2], .MenuItem = 0, .Target = &oledScreens[3], .Parameter = 0},
    {.Source = &oledScreens[2], .MenuItem = 1, .Target = &oledScreens[3], .Parameter = 1},
    {.Source = &oledScreens[2], .MenuItem = 2, .Target = &oledScreens[3], .Parameter = 2},
    {.Source = &oledScreens[2], .MenuItem = 3, .Target = &oledScreens[3], .Parameter = 3},
    {.Source = &oledScreens[2], .MenuItem = 4, .Target = &oledScreens[4]},
    {.Source = &oledScreens[2], .MenuItem = 5, .Target = &oledScreens[5]},
    {.Source = &oledScreens[2], .MenuItem = 6, .Target = &oledScreens[6]},
    {.Source = &oledScreens[2], .MenuItem = 7, .Target = &oledScreens[7]},
};

static const unsigned char oledTransitions = 9;

static OLED_State oledState = {.State = OLEDM_Offline, .ActiveScreen = &oledScreens[0], .OnRender = NULL, .OnNavigate = NULL};

void OLED_Init() {
    // Do not enable OLED if subboard is not detected
    if ((GPIOB->IDR & (1 << 15)) == 0) {
        return;
    }

    GPIOB->MODER |= (0x3 << GPIO_MODER_MODE15_Pos);
    oledState.State = OLEDM_Active;

    // Initialize I²C & DMA
    DMAMUX1_Channel8->CCR = 23; // I2C4_TX (RX=22)

    // Timings for 100kHz @ 143.75MHz as given by CubeMX
    I2C4->TIMINGR = 0x20B0D8FF;
    I2C4->CR2 |= I2C_CR2_AUTOEND;
    I2C4->CR1 |= I2C_CR1_PE | I2C_CR1_TCIE | I2C_CR1_STOPIE;

    NVIC_SetPriority(I2C4_EV_IRQn, 16);
    NVIC_EnableIRQ(I2C4_EV_IRQn);

    SSD1306_Init(OLED_InitSendData);

    lastTick = sys_now();
    bootTimer = sys_now();
}
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

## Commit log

2022-11-06 Bugfix for DMX Transmit
    USART-Clock now uses HSE
    [dmx_usart.c, main.c]
2022-11-06 Added schematic and pcb layout
    [DMX-B_Cu.gbl, DMX-B_Mask.gbs, DMX-B_Paste.gbp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]
2022-11-06 Added some images for readme
    [DMX.sch]
2022-12-01 Outputs/Inputs can now be configured using the resistors
    Fixes #1
    [main.c]
2023-01-10 DMX Output via ArtNet works now
    Emergency COM-Port if device is broken
    Switch to bootloader possible
    Doubled the core clock speed
    [dmx_usart.c]
2023-02-08 Some Bugfixes & ArtNet features
    - Store ACN Priority in config
    - Support for Failover modes
    - Fix Bug when changing port mode to delta
    - Support to override port direction with ArtNET
    - Store Port Flags (Delta-Mode & RDM) in config
    - ArtNET Timeout to detect inactive ports for failover
    - Store Failover-Scene in Flashpage
    [dmx_usart.c]
2023-02-09 Faster USB-Enumeration
    Forgot to reject the Request for a qualifier descriptor used for High Speed devices
2023-02-09 Fix bugs in ArtNET Input ports
    [main.c]
2023-02-10 First completely working ArtNET version
    Added profiling feature to ignore sessions after they started
    Doubled the AHB clock, now it works stable somehow?
    Better Input handling without dropping packets
    Missing: Still some serial commands
    [dmx_usart.c, main.c]
2023-02-27 Bugfix for DMX Input
    Fixed off-by-1 bug in the compiler optimized firmware
    Added D0 command to dump dmx buffers for Debug purposes via serial
    [dmx_usart.c]
2023-02-28 Bugfix for serial device detection
2023-03-06 Bugfix for receiving non-DMX packets and flickering
    [dmx_usart.c]
2023-05-29 Started new Hardware Revision
    Fixes #6
    [BOM.xlsx, DMX Subboard.csv, DMX Subboard.kicad_pcb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]
2023-06-12 Porting Code to new MCU
    - Add BOM at digikey
    - Adjusting port config to dip switches
    - More resources to lwip stack
    [DMX Subboard.kicad_pcb]
2023-07-07 First OLED support
    - SSD1306 support added
    - OLED menu added (wip)
    [DMX Subboard.kicad_pcb, DMX Subboard.kicad_sch]
2023-07-12 Some minor bugfixes
    - Implemented reset button
    - "Fixed" timing bug with OLED initialization
    - Fixed Release Build
    - Fixed Flash settings
    [main.c, oled.c]
2023-07-14 Added Cutout specifications
    [Cover.FCStd]
2023-07-24 Added support for different OLED-pinning
    [DMX Subboard.kicad_pcb, DMX Subboard.kicad_sch]
2023-07-29 CAD adjustments
    - Adjusted Distance of front XLR, was too close to cover border
    - Adjusted Milling parameters for my CNC: The plastic melts really fast.
    100mm/m | 0.5mm @ 10.000RPM worked for me with acceptable burring.
    Cleaning up with a knife was necessary afterwards though
    [Cover.FCStd]
2023-08-08 Fixing all the configuration issues
    OLED:
    - Hardfault when up/down button was pressed in IP overview
    - ArtNET-Universe was not set correctly
    - Description text did not scroll correctly
    Flash:
    - Reset status correctly when clearing config page
    - Don't purge flash on every power up
    ArtNet:
    - Did not report input universe correctly
    - Failover state was applied continuously, resulting in cpu hogging
    Web Interface:
    - Added display of Firmware ID / Version
    - Fixed bug in IP-Options regarding checkboxes
    - Deferred network apply until after post request was handled
    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
    [Testdoc.xlsx]
2023-08-08 Fixed bug in initialization of first port
    - All tests completed
    [Testdoc.xlsx]
2023-08-08 Fixing most of the Warnings
    [oled.c]
2024-04-07 Some bugfixes for input ports
    - New Input is now triggered correctly
    [usart.c]
2024-12-16 Fixed bug in USB handler that prevented iPads from using this device
    Fixes #13
